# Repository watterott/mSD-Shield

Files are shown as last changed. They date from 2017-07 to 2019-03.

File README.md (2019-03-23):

# mSD-Shield
The mSD-Shield is a plug-on module with microSD socket, RTC (real time clock) with battery backup, prototyping area and optional 2.8" TFT-Display with Touch-Panel for Arduino.

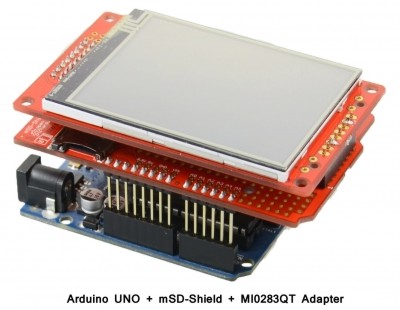
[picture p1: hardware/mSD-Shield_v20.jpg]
mSD-Shield


* microSD socket (SPI) support SD and SDHC cards
* DS1307 RTC (I2C Real-Time-Clock) with backup battery
* On-board 3.3V voltage regulator
* Optional MI0283QT-Adapter (2.8" 320x240 Display with Touch-Panel)
* Prototyping Area
* Open-Source and released under the [Creative Commons Attribution Share-Alike License](https://creativecommons.org/licenses/by-sa/4.0/).
* **[Documentation on learn.watterott.com](https://learn.watterott.com)**

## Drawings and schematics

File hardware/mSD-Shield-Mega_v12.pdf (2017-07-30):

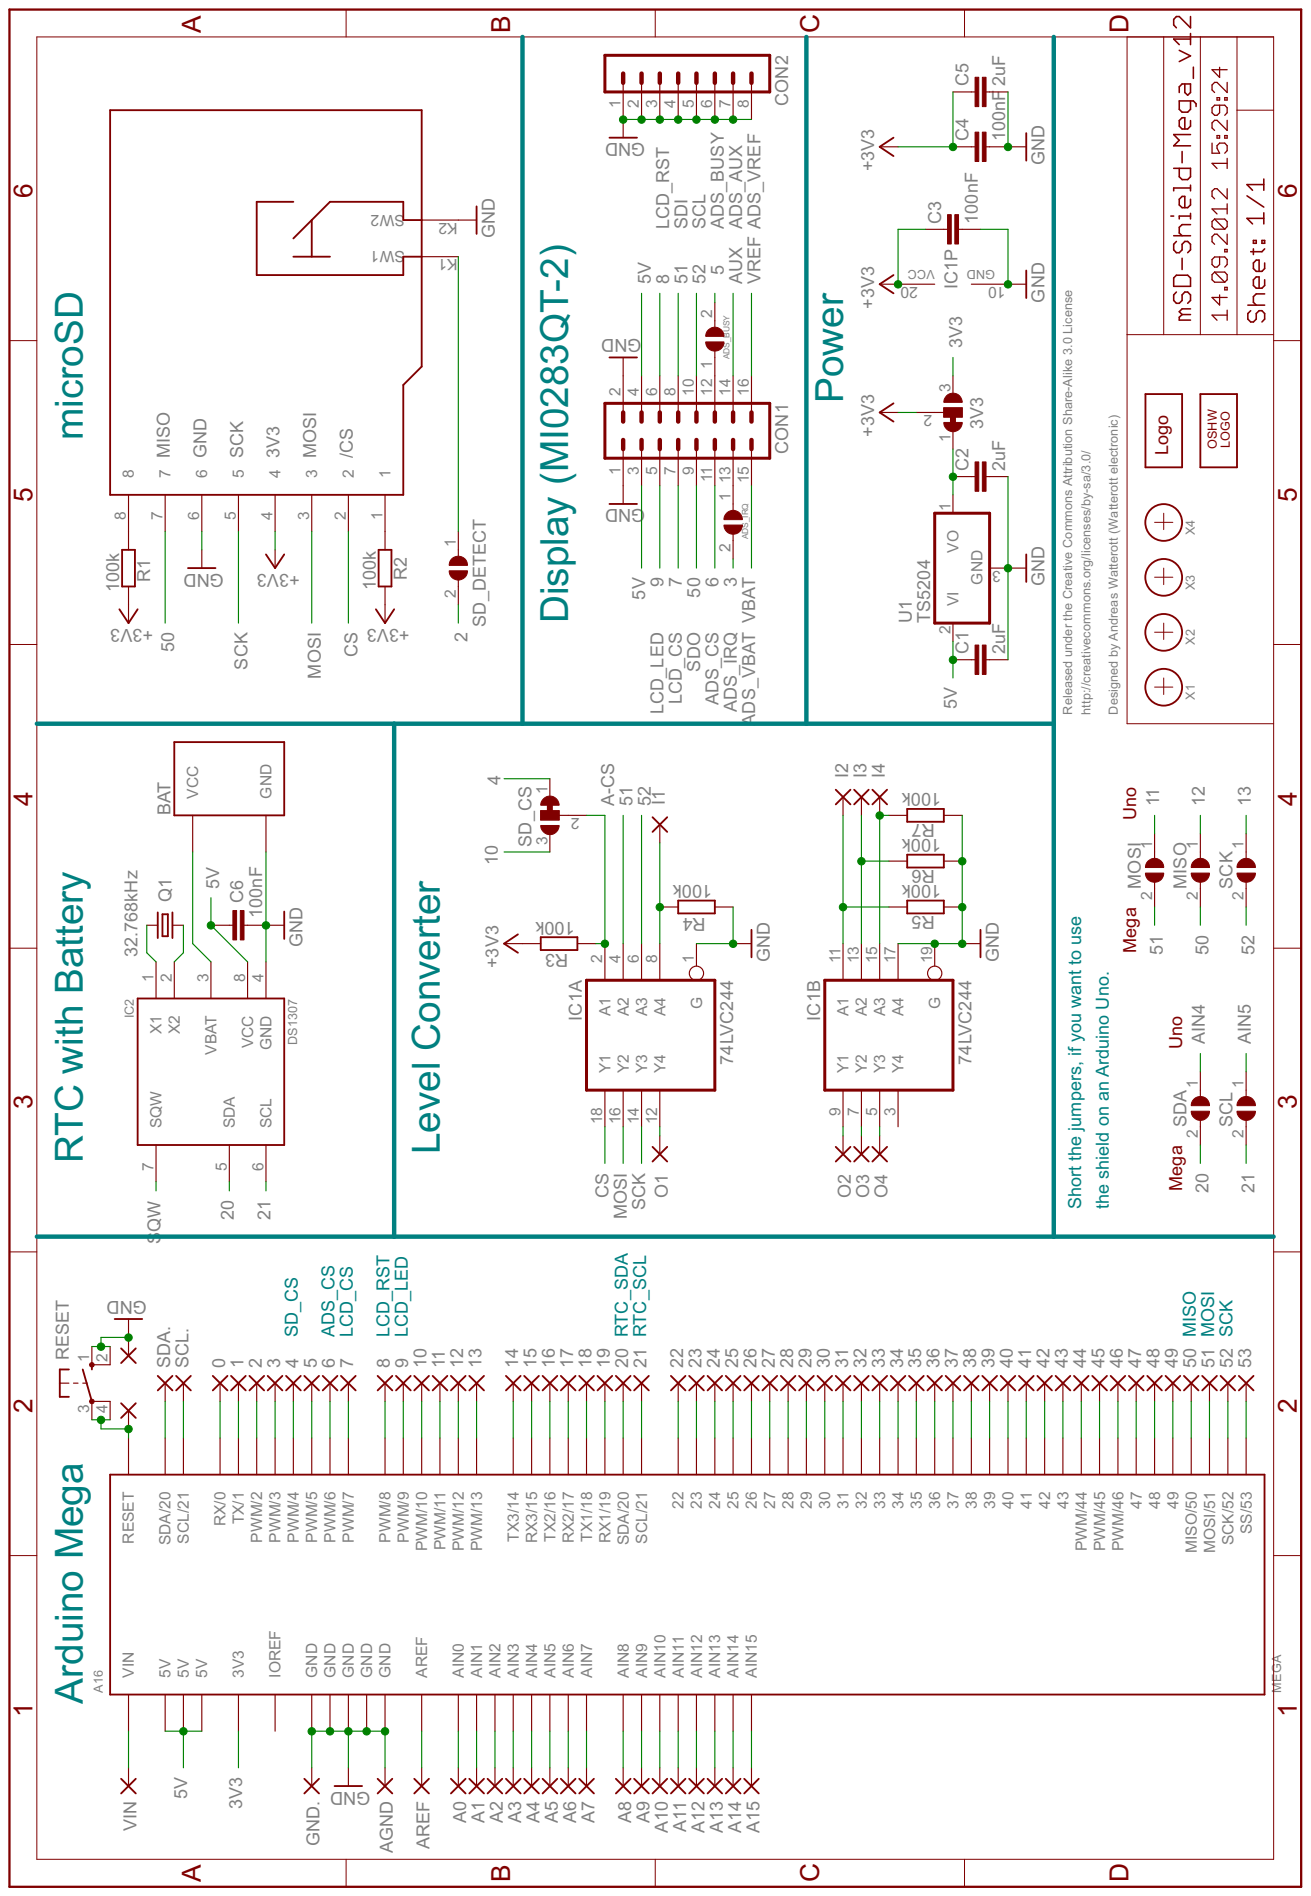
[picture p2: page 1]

Released under the Creative Commons Attribution Share-Alike 3.0 License

http://creativecommons.org/licenses/by-sa/3.0/ Designed by Andreas Watterott (Watterott electronic)

2 4 RESET SDA. SCL. GND

Uno Mega Mega Uno

Short the jumpers, if you want to use

the shield on an Arduino Uno. SCK M

PWM/3 PWM/4 PWM/5 PWM/6 PWM/7 PWM/8 PWM/9 PWM/10 PWM/11 PWM/12 PWM/13 AIN1 AIN2 AIN3 AIN4 AIN5

49 MISO/50 MOSI/51 SCK/52 SS/53

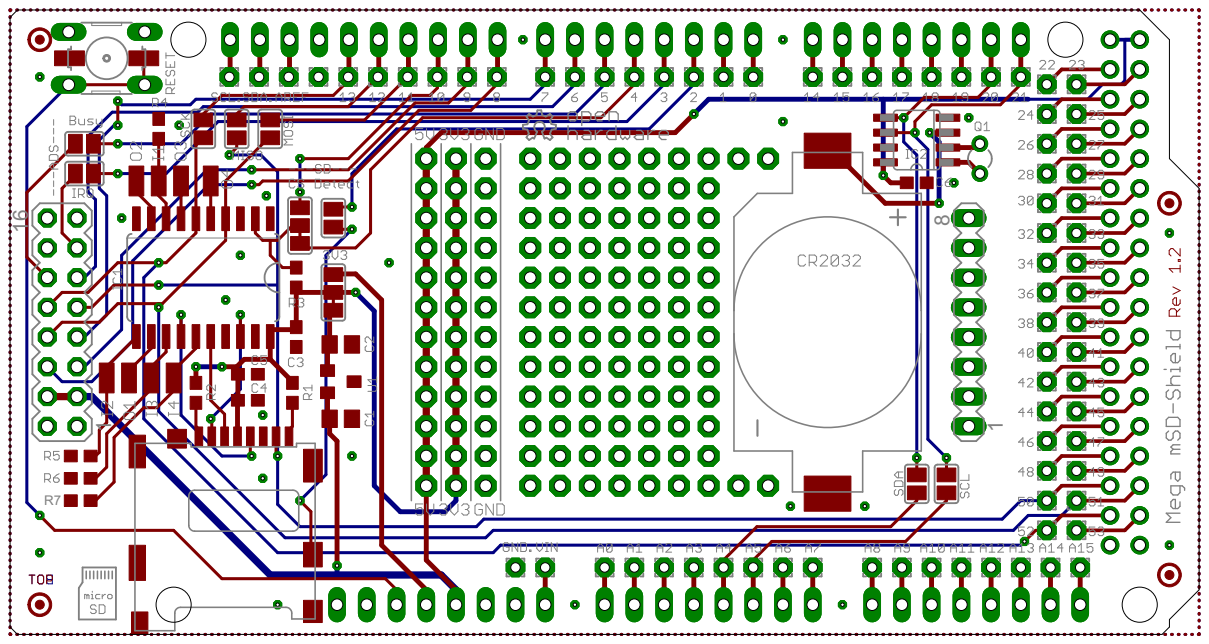
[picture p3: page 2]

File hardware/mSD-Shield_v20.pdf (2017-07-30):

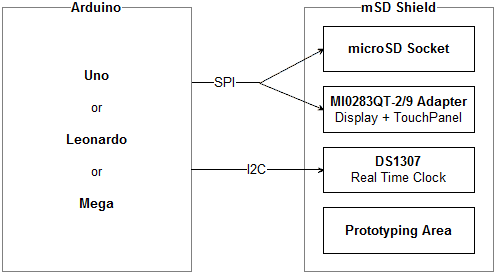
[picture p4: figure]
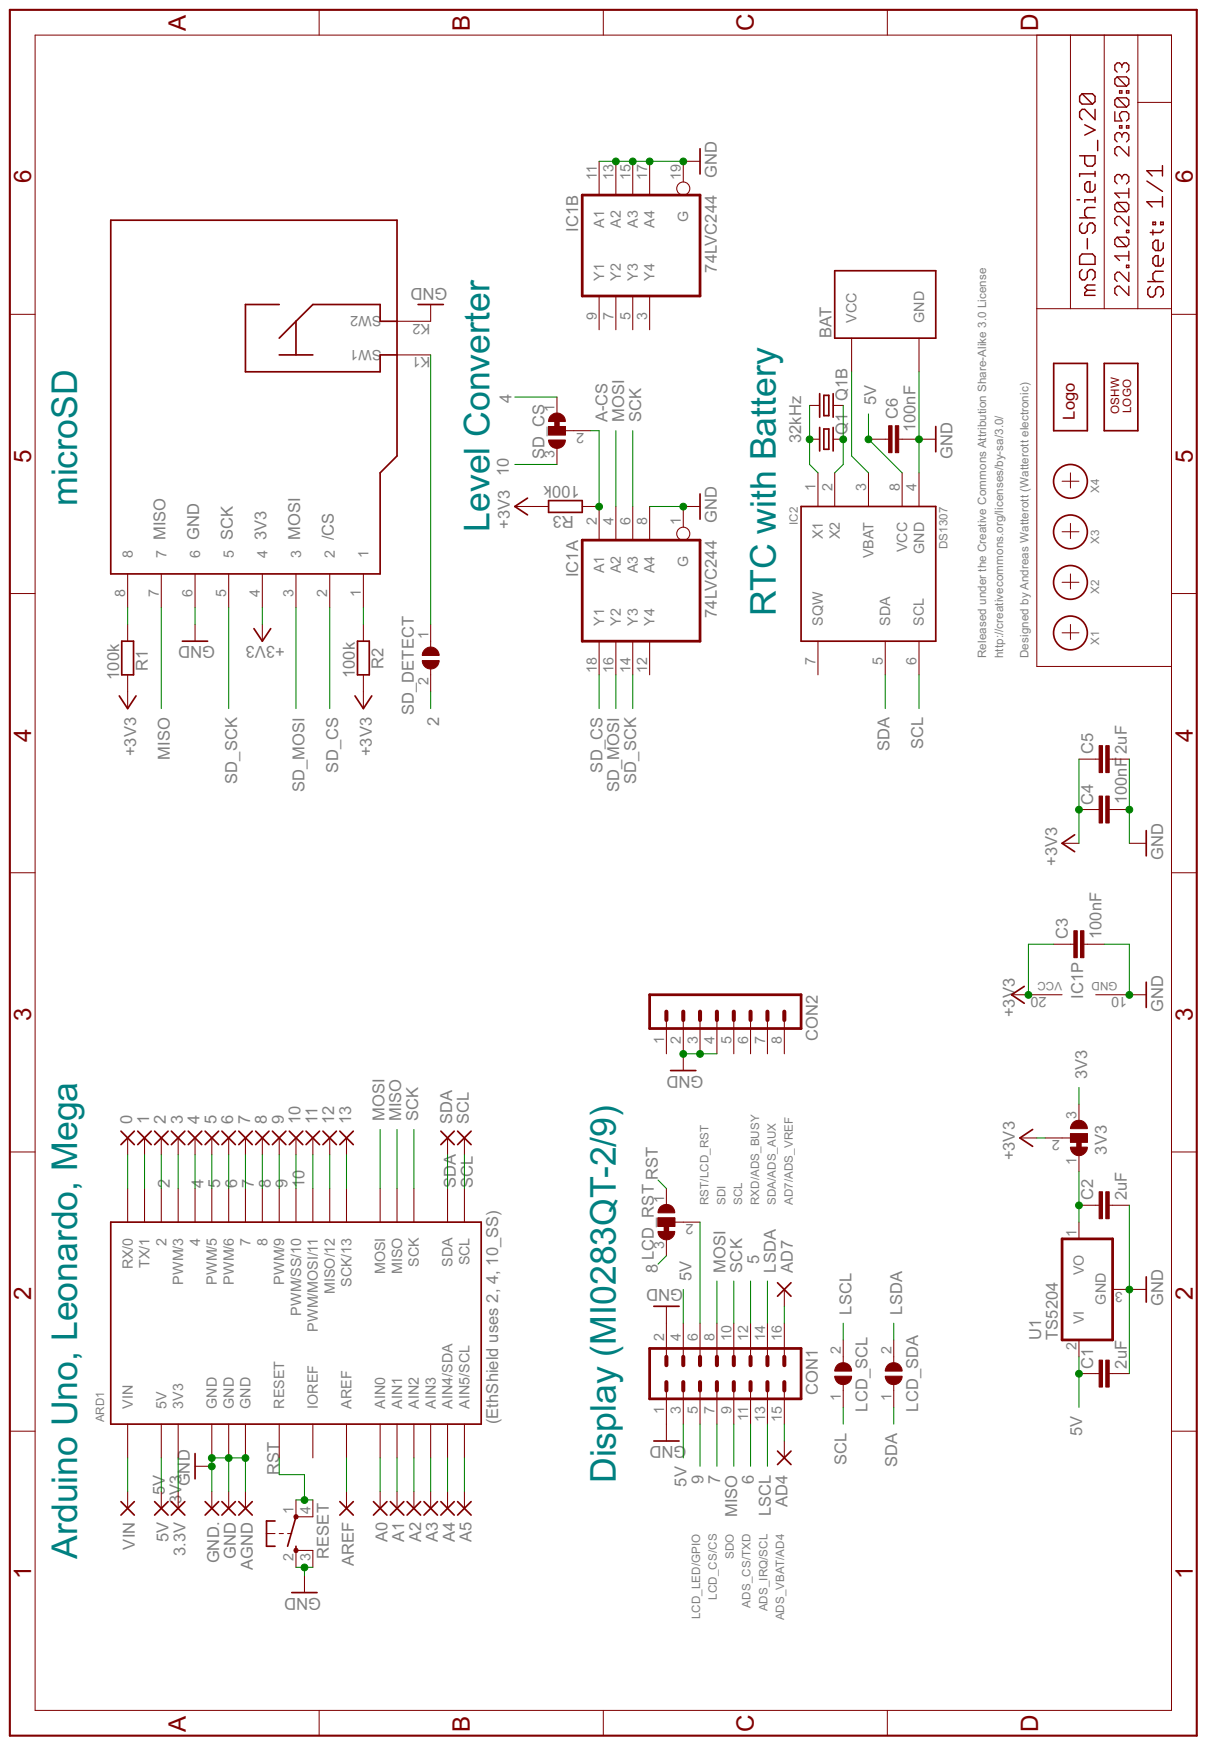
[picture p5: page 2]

Released under the Creative Commons Attribution Share-Alike 3.0 License

Arduino Uno, Leonardo, Mega microSD

Designed by Andreas Watterott (Watterott electronic)

http://creativecommons.org/licenses/by-sa/3.0/

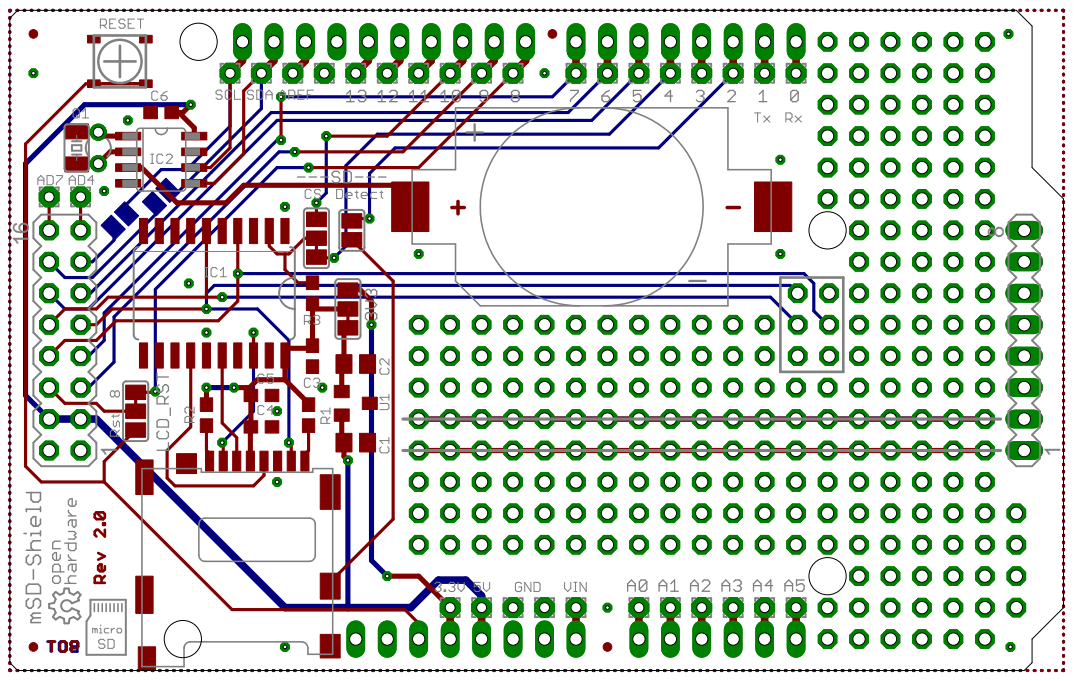
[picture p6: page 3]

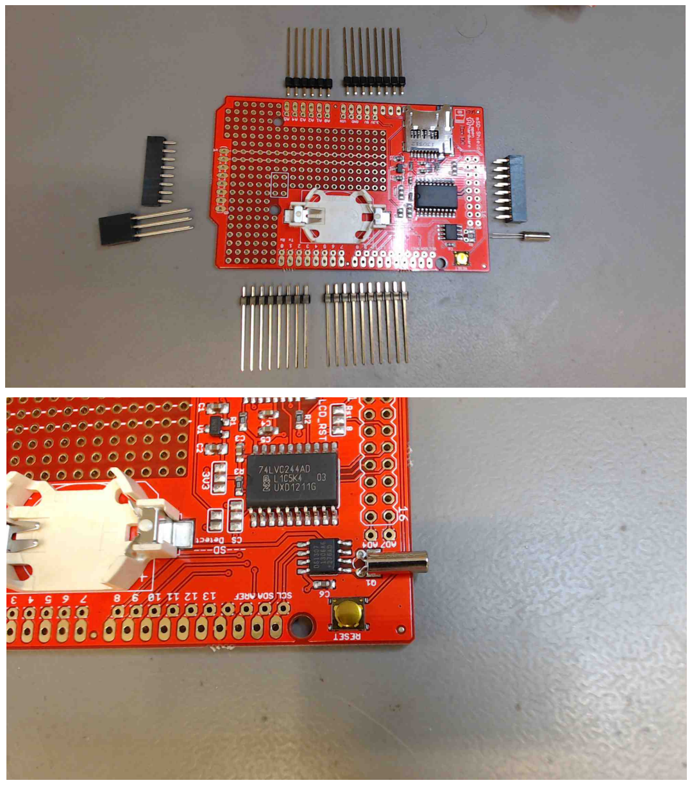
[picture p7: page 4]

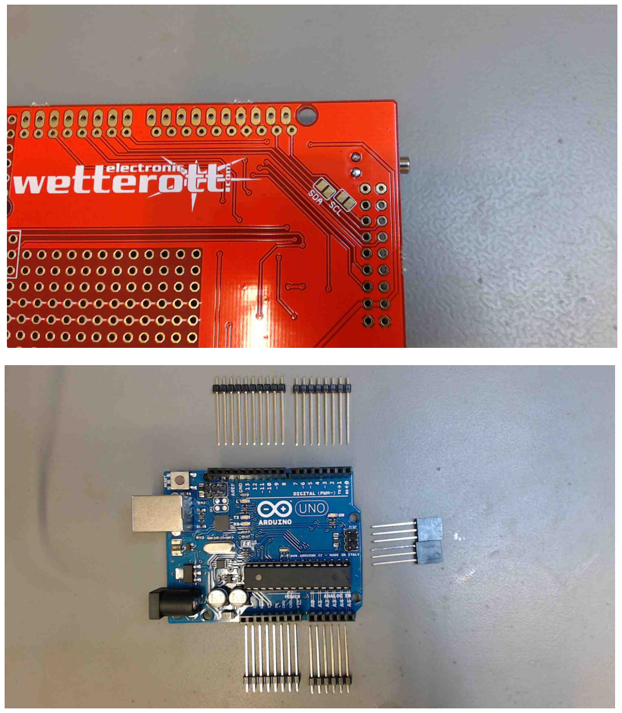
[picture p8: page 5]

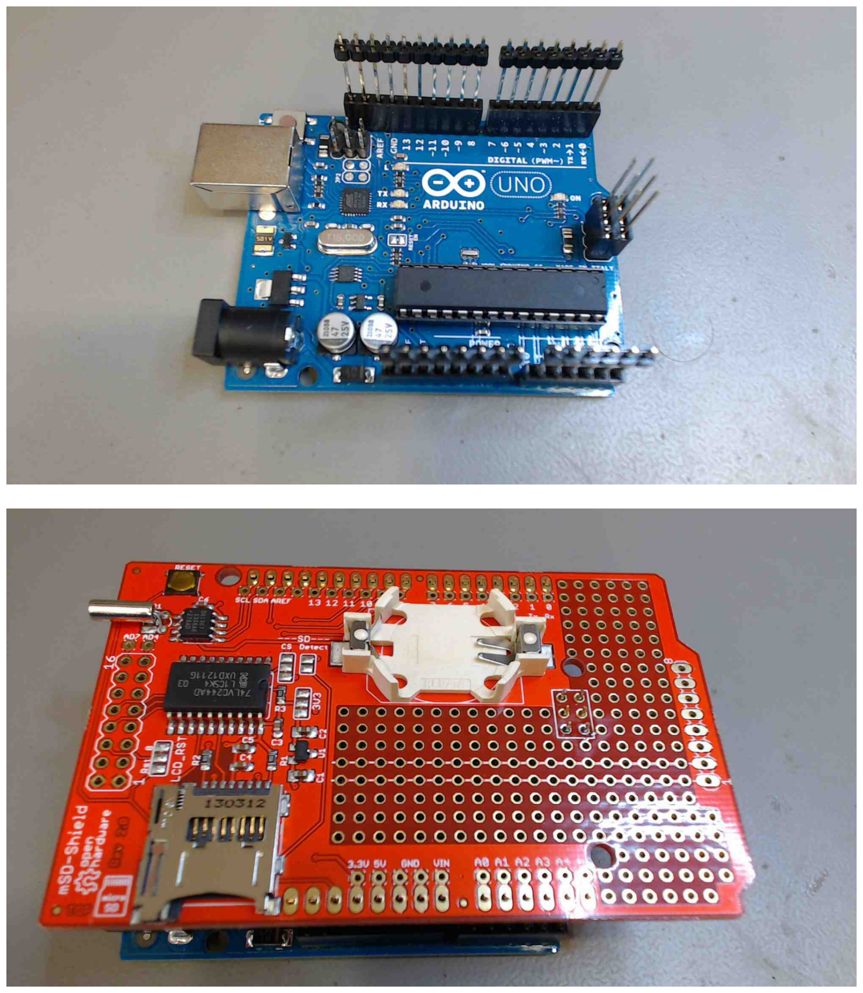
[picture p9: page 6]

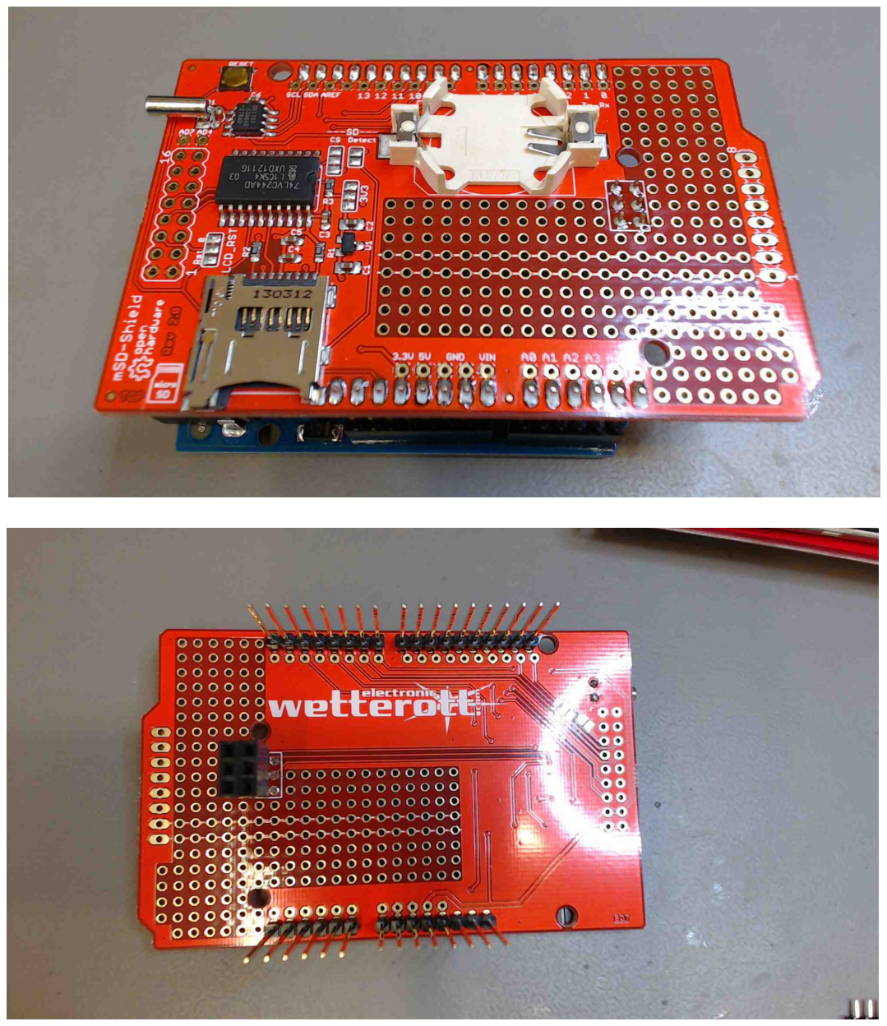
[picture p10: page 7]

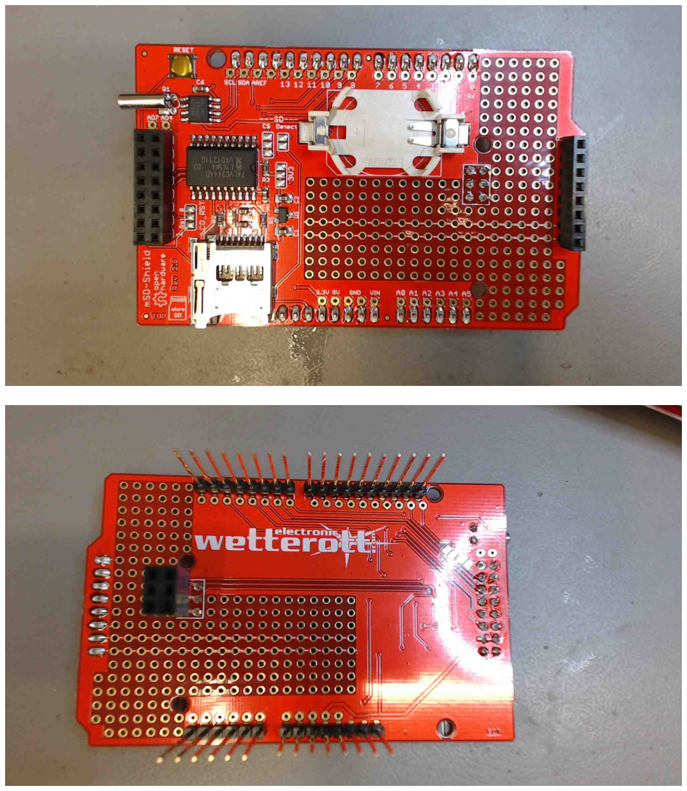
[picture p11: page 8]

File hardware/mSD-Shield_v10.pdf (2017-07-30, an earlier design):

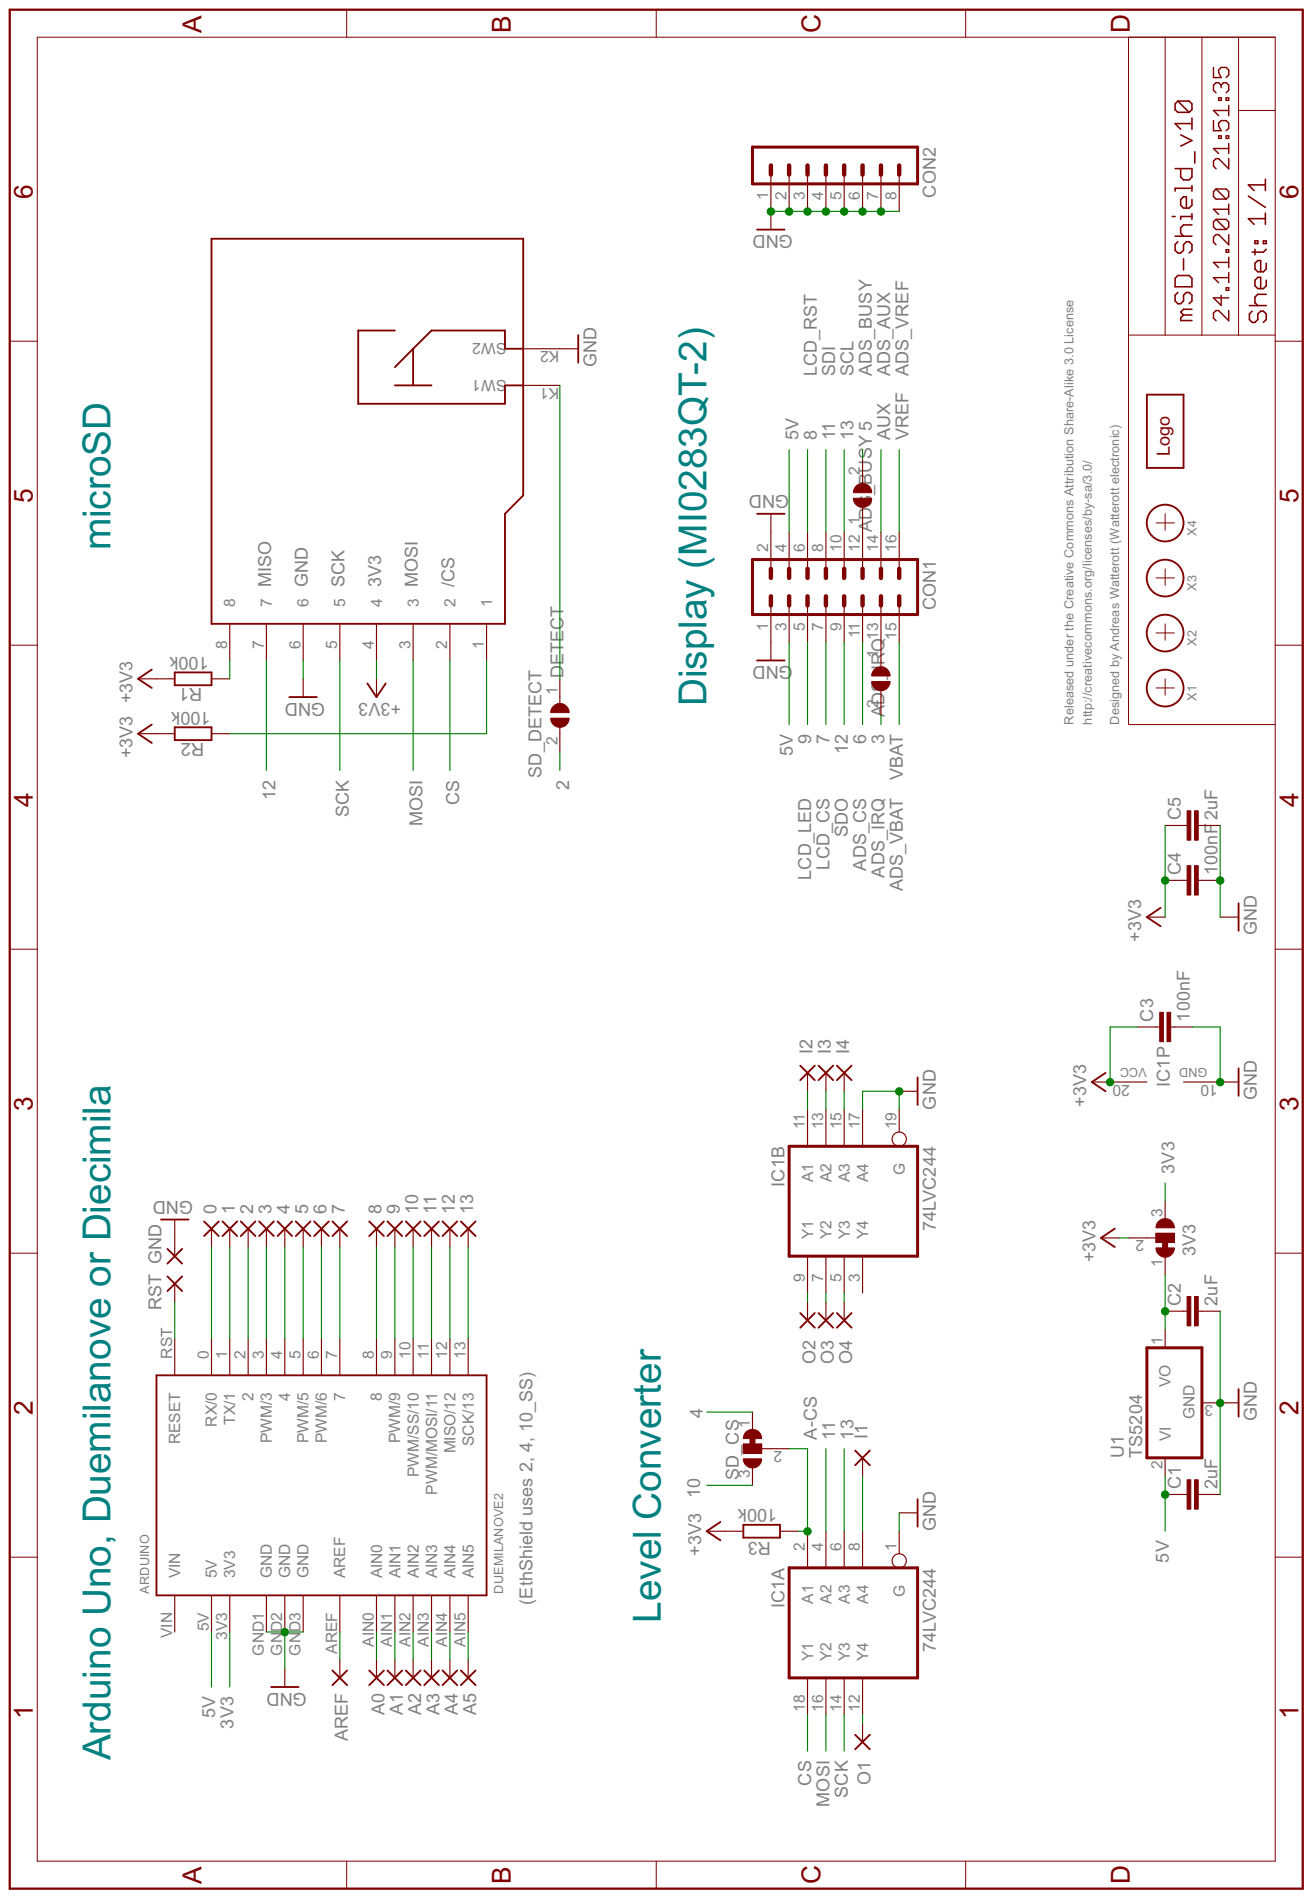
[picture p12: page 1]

TS5204 GND 2uF 2uF 100nF +3V3 GND 2uF 74LVC244 74LVC244 GND +3V3 100nF GND GND k001 +3V3 DNG 3V3+ k001 k001 +3V3 +3V3 GND DNG DNG DNG +3V3 DNG DNG Released under the Creative Commons Attribution Share-Alike 3.0 License http://creativecommons.org/licenses/by-sa/3.0/ Designed by Andreas Watterott (Watterott electronic) (EthShield uses 2, 4, 10_SS) LCD_LED LCD_CS SDO ADS_CS ADS_IRQ ADS_VBAT ADS_VREF ADS_AUX ADS_BUSY SCL SDI LCD_RST VI 2 3 VO 1 GND U1 C1 C2 C4 C5 G 1 A1 2 A2 4 A3 6 A4 8 Y4 12 Y3 14 Y2 16 Y1 18 IC1A G 19 A1 11 A2 13 A3 15 A4 17 Y4 3 Y3 5 Y2 7 Y1 9 IC1B 02 01 CCV DNG IC1P C3 3R 1 1 2 2 3 3 4 4 5 5 6 6 7 7 8 8 1 WS 1K 2 WS 2K /CS SCK MOSI MISO GND 3V3 1R2R 12345678CON2 135 246 79 810 111315 121416 CON1 3 1 2 3V3 3 1 2 SD_CS 2 1ADS_BUSY 2 1 SD_DETECT 2 1 ADS_IRQ ARDUINO DUEMILANOVE2 RX/0 0 TX/1 1 2 2 AIN0 AIN0 PWM/3 3 4 4 PWM/5 5 PWM/6 6 7 7 8 8 PWM/9 9 PWM/SS/10 10 PWM/MOSI/11 11 MISO/12 12 SCK/13 13 AIN1 AIN1 AIN2 AIN2 AIN3 AIN3 AIN4 AIN4 AIN5 AIN5 5V 5V GND GND1 GND GND2 VIN VIN 3V3 3V3 GND GND3 AREF AREF RESET RST RST GND X1 X2 X3 X4 012345678910111213 A0A1A2A3A4A5 AREF I1 I2I3I4 O1 O2 O3 O4 76 5 4 3 2 SCK SCK MOSI MOSI CS CS 13 13 12 12 11 11 9 8 5V 5V 5V 5V 3V3 3V3 DETECT AUX VBAT VREF A-CS 10 ABCD 1 2 3 4 5 6 ABCD 1 2 3 4 5 6 Logo Arduino Uno, Duemilanove or Diecimila microSD Level Converter Display (MI0283QT-2)

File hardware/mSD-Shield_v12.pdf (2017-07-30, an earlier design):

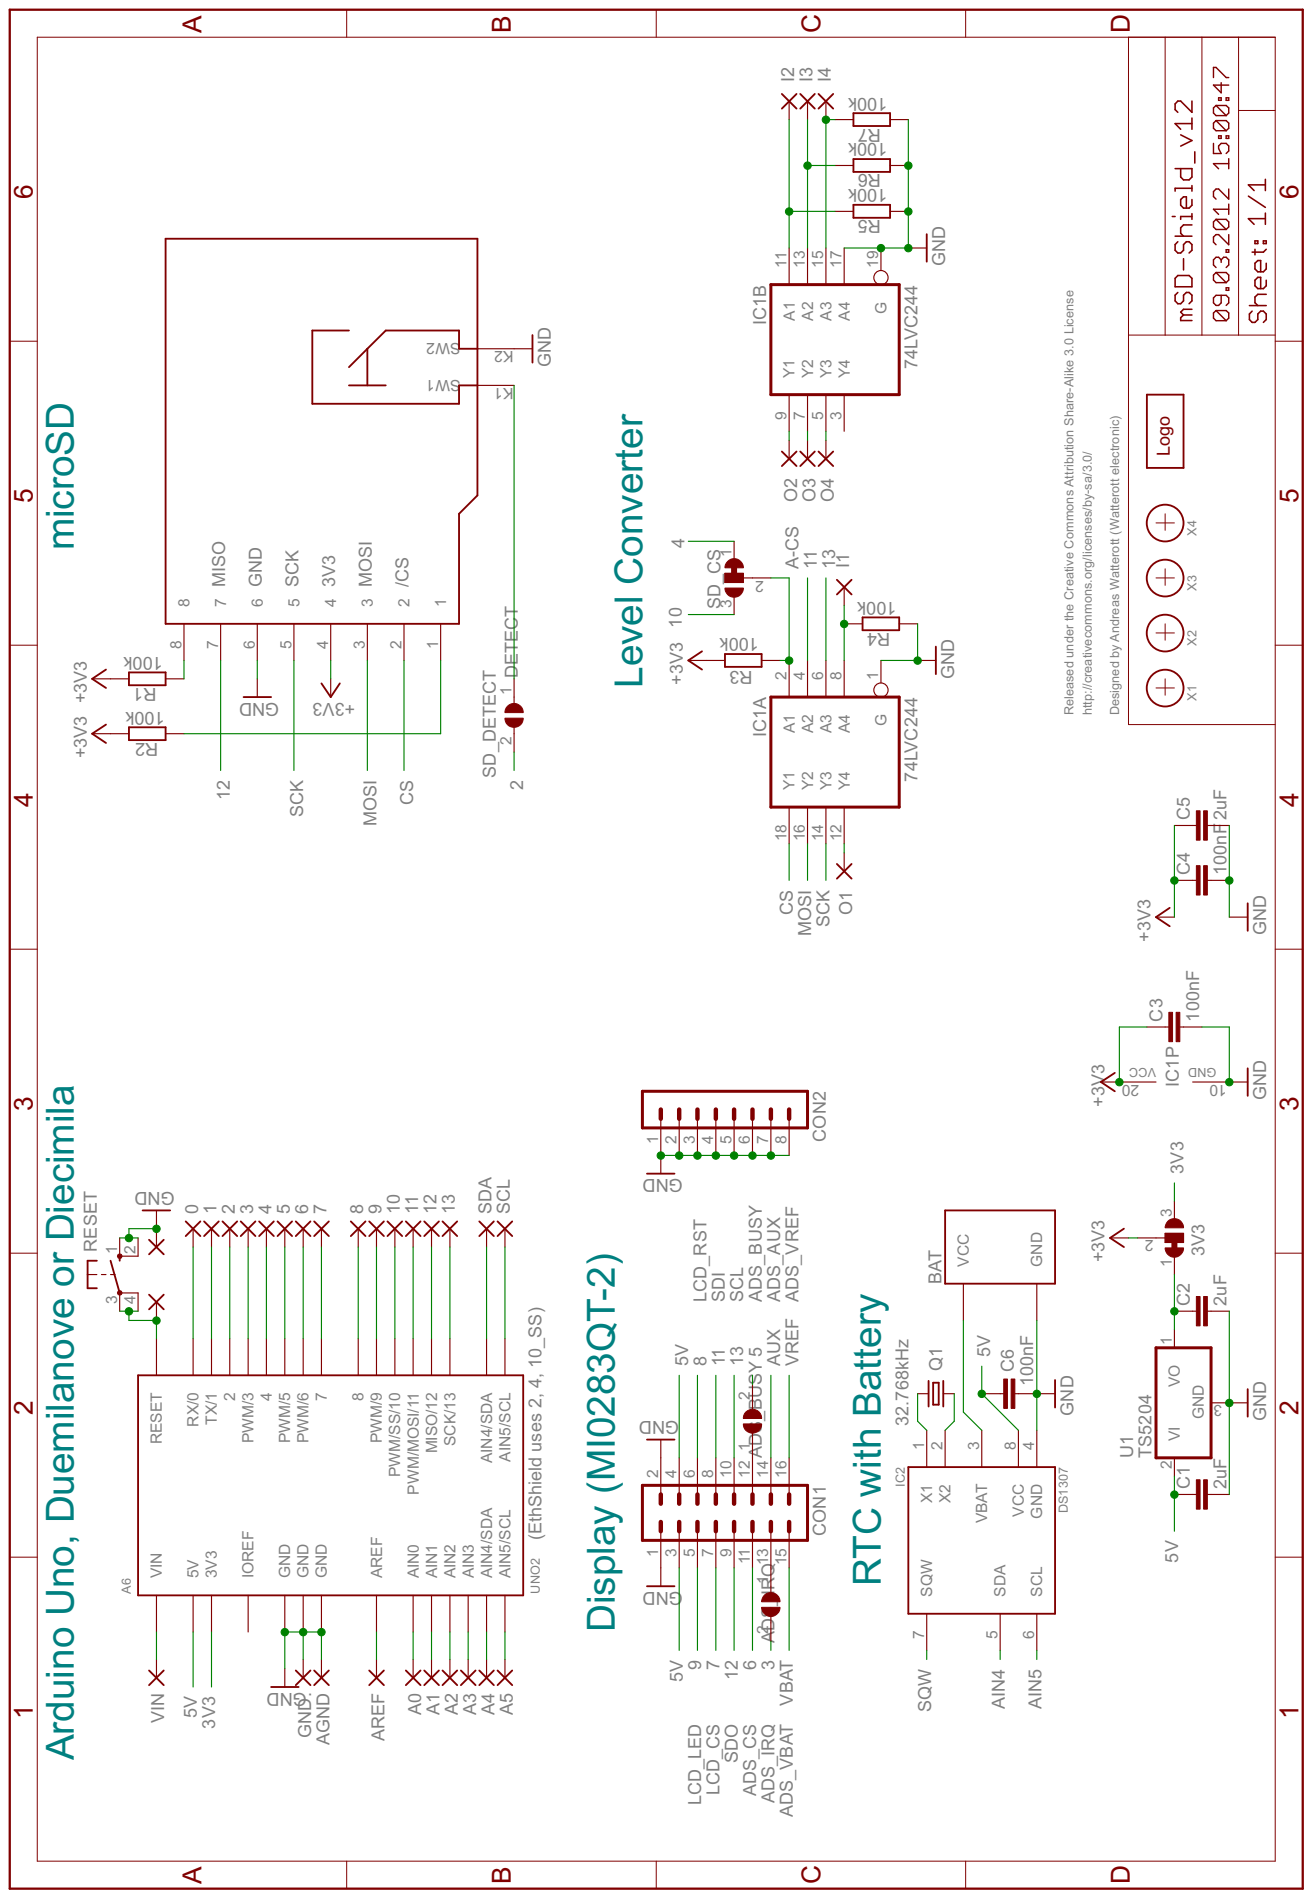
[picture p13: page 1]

Released under the Creative Commons Attribution Share-Alike 3.0 License

http://creativecommons.org/licenses/by-sa/3.0/ Designed by Andreas Watterott (Watterott electronic)

8 PWM/9 PWM/SS/10 PWM/MOSI/11 MISO/12 SCK/13 AIN1 AIN2 AIN3 AIN4/SDA

IOREF GND GND GND


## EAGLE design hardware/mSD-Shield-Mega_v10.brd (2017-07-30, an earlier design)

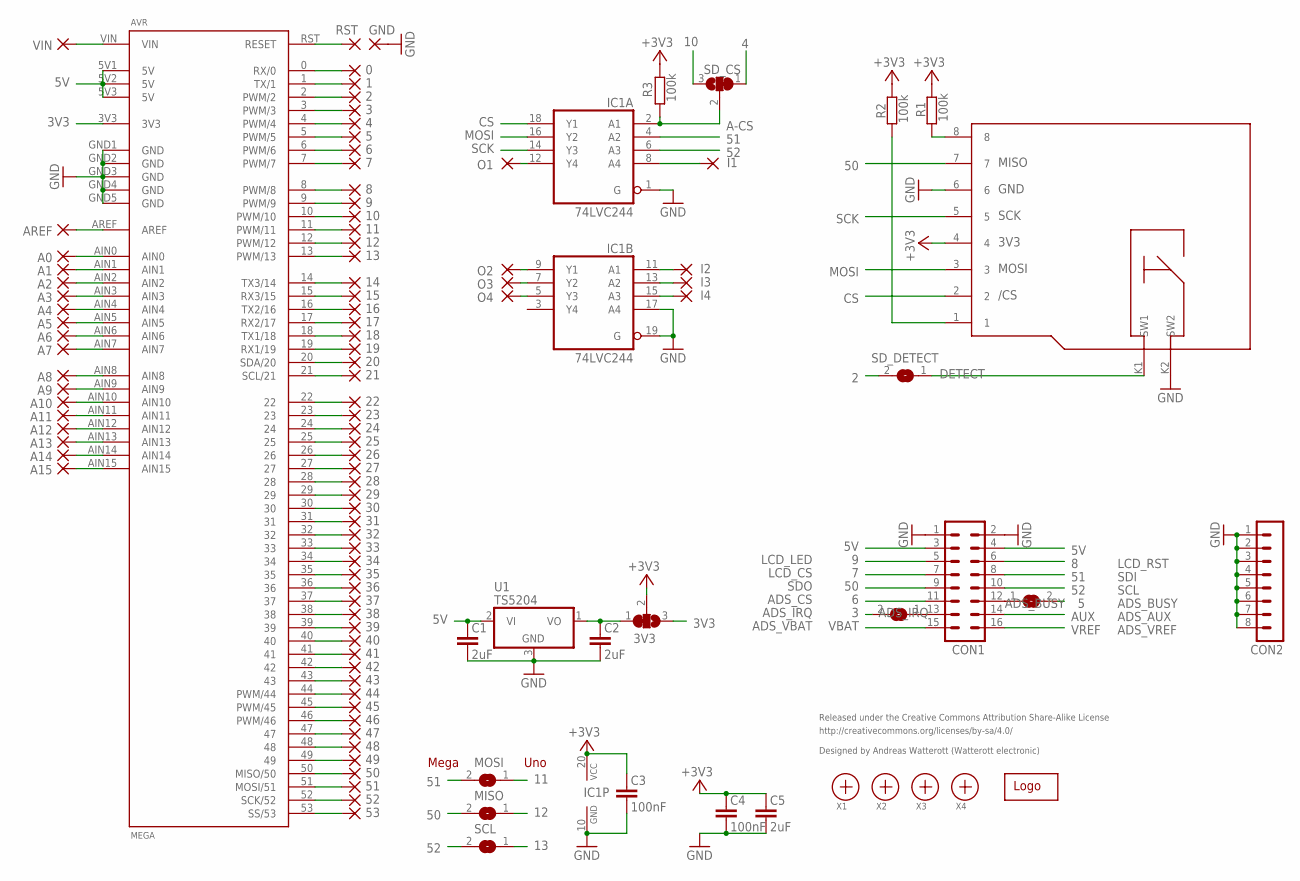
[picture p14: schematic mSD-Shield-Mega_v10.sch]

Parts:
0, 1, 2, 3, 4, 5, 6, 7, 8, 9, 10, 11, 12, 13, 14, 15, 16, 17, 18, 19, 20, 21, 22, 23, 24, 25, 26, 27, 28, 29, 30, 31, 32, 33, 34, 35, 36, 37, 38, 39, 40, 41, 42, 43, 44, 45, 46, 47, 48, 49, 50, 51, 52, 53: 1,6/0,8
3V3: SJ2W; SJ_2
A0, A1, A2, A3, A4, A5, A6, A7, A8, A9, A10, A11, A12, A13, A14, A15: 1,6/0,8
ADS_BUSY: SJ
ADS_IRQ: SJ
AREF: 1,6/0,8
AVR: MEGA
C1, C2: 2uF; C0805
C3, C4: 100nF; C0603
C5: 2uF; C0603
CON1: MA08-2
CON2: MA08-1
GND: SMD2; SMD1,27-2,54
I1, I2, I3, I4: SMD2; SMD1,27-2,54
IC1: 74LVC244; SO20W
MISO: SJ
MOSI: SJ
O1, O2, O3, O4: SMD2; SMD1,27-2,54
R1, R2, R3: 100k; R0603
RST: SMD2; SMD1,27-2,54
SCL: SJ
SD_CS: SJ2W; SJ_2
SD_DETECT: SJ
U1: TS5204; SOT23
U$1: WE-LOGO
VIN: 1,6/0,8
X1, X2, X3, X4: PASSER
X5: MICRO-SD

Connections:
0: 0.1, AVR.0 (RX/0)
1: 1.1, AVR.1 (TX/1)
2: 2.1, AVR.2 (PWM/2), SD_DETECT.2
3: 3.1, ADS_IRQ.2, AVR.3 (PWM/3)
3V3: 3V3.3, AVR.3V3
3V_OUT: 3V3.1, C2.1, U1.1 (VO)
4: 4.1, AVR.4 (PWM/4), SD_CS.1
5: 5.1, ADS_BUSY.2, AVR.5 (PWM/5)
5V: AVR.5V1 (5V), AVR.5V2 (5V), AVR.5V3 (5V), C1.1, CON1.3, CON1.4, U1.2 (VI)
6: 6.1, AVR.6 (PWM/6), CON1.11
7: 7.1, AVR.7 (PWM/7), CON1.7
8: 8.1, AVR.8 (PWM/8), CON1.6
9: 9.1, AVR.9 (PWM/9), CON1.5
10: 10.1, AVR.10 (PWM/10), SD_CS.3
11: 11.1, AVR.11 (PWM/11), MOSI.1
12: 12.1, AVR.12 (PWM/12), MISO.1
13: 13.1, AVR.13 (PWM/13), SCL.1
14: 14.1, AVR.14 (TX3/14)
15: 15.1, AVR.15 (RX3/15)
16: 16.1, AVR.16 (TX2/16)
17: 17.1, AVR.17 (RX2/17)
18: 18.1, AVR.18 (TX1/18)
19: 19.1, AVR.19 (RX1/19)
20: 20.1, AVR.20 (SDA/20)
21: 21.1, AVR.21 (SCL/21)
22: 22.1, AVR.22
23: 23.1, AVR.23
24: 24.1, AVR.24
25: 25.1, AVR.25
26: 26.1, AVR.26
27: 27.1, AVR.27
28: 28.1, AVR.28
29: 29.1, AVR.29
30: 30.1, AVR.30
31: 31.1, AVR.31
32: 32.1, AVR.32
33: 33.1, AVR.33
34: 34.1, AVR.34
35: 35.1, AVR.35
36: 36.1, AVR.36
37: 37.1, AVR.37
38: 38.1, AVR.38
39: 39.1, AVR.39
40: 40.1, AVR.40
41: 41.1, AVR.41
42: 42.1, AVR.42
43: 43.1, AVR.43
44: 44.1, AVR.44 (PWM/44)
45: 45.1, AVR.45 (PWM/45)
46: 46.1, AVR.46 (PWM/46)
47: 47.1, AVR.47
48: 48.1, AVR.48
49: 49.1, AVR.49
50: 50.1, AVR.50 (MISO/50), CON1.9, MISO.2, X5.7
51: 51.1, AVR.51 (MOSI/51), CON1.8, IC1.4 (A2), MOSI.2
52: 52.1, AVR.52 (SCK/52), CON1.10, IC1.6 (A3), SCL.2
53: 53.1, AVR.53 (SS/53)
+3V3: 3V3.2, C3.1, C4.1, C5.1, IC1.20 (VCC), R1.1, R2.1, R3.2, X5.4
A-CS: IC1.2 (A1), R3.1, SD_CS.2
ADS_BUSY: ADS_BUSY.1, CON1.12
ADS_IRQ: ADS_IRQ.1, CON1.13
AIN0: A0.1, AVR.AIN0
AIN1: A1.1, AVR.AIN1
AIN2: A2.1, AVR.AIN2
AIN3: A3.1, AVR.AIN3
AIN4: A4.1, AVR.AIN4
AIN5: A5.1, AVR.AIN5
AIN6: A6.1, AVR.AIN6
AIN7: A7.1, AVR.AIN7
AIN8: A8.1, AVR.AIN8
AIN9: A9.1, AVR.AIN9
AIN10: A10.1, AVR.AIN10
AIN11: A11.1, AVR.AIN11
AIN12: A12.1, AVR.AIN12
AIN13: A13.1, AVR.AIN13
AIN14: A14.1, AVR.AIN14
AIN15: A15.1, AVR.AIN15
AUX: CON1.14
CS: IC1.18 (Y1), X5.2
DETECT: SD_DETECT.1, X5.K1 (SW1)
GND: AVR.GND1 (GND), AVR.GND2 (GND), AVR.GND3 (GND), AVR.GND4 (GND), AVR.GND5 (GND), C1.2, C2.2, C3.2, C4.2, C5.2, CON1.1, CON1.2, CON2.1, CON2.2, CON2.3, CON2.4, CON2.5, CON2.6, CON2.7, CON2.8, GND.1, IC1.1 (G), IC1.10 (GND), IC1.17 (A4), IC1.19 (G), U1.3 (GND), X5.6, X5.K2 (SW2)
I-1: I1.1, IC1.8 (A4)
I-2: I2.1, IC1.11 (A1)
I-3: I3.1, IC1.13 (A2)
I-4: I4.1, IC1.15 (A3)
MOSI: IC1.16 (Y2), X5.3
unnamed: R2.2, X5.1
unnamed: R1.2, X5.8
unnamed: AVR.VIN, VIN.1
unnamed: AREF.1, AVR.AREF
O-1: IC1.12 (Y4), O1.1
O-2: IC1.9 (Y1), O2.1
O-3: IC1.7 (Y2), O3.1
O-4: IC1.5 (Y3), O4.1
RST: AVR.RST (RESET), RST.1
SCK: IC1.14 (Y3), X5.5
VBAT: CON1.15
VREF: CON1.16

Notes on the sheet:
Released under the Creative Commons Attribution Share-Alike License
http://creativecommons.org/licenses/by-sa/4.0/
Designed by Andreas Watterott (Watterott electronic)
LCD_LED
LCD_CS
SDO
ADS_CS
ADS_IRQ
ADS_VBAT
ADS_VREF
ADS_AUX
ADS_BUSY
SCL
SDI
LCD_RST
Uno
Mega

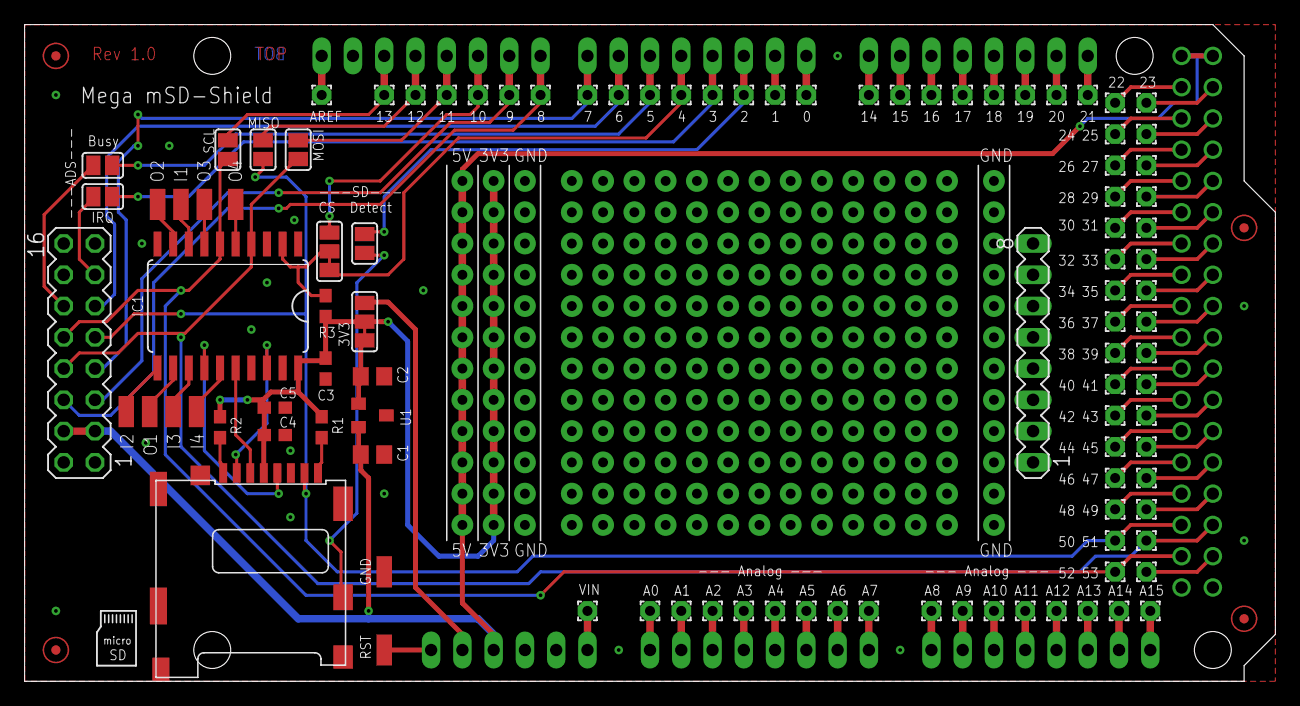
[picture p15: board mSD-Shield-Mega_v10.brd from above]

Board: 2 copper layers, 101.6 x 53.3 mm, 109 parts (1 on the bottom side), 95 nets.

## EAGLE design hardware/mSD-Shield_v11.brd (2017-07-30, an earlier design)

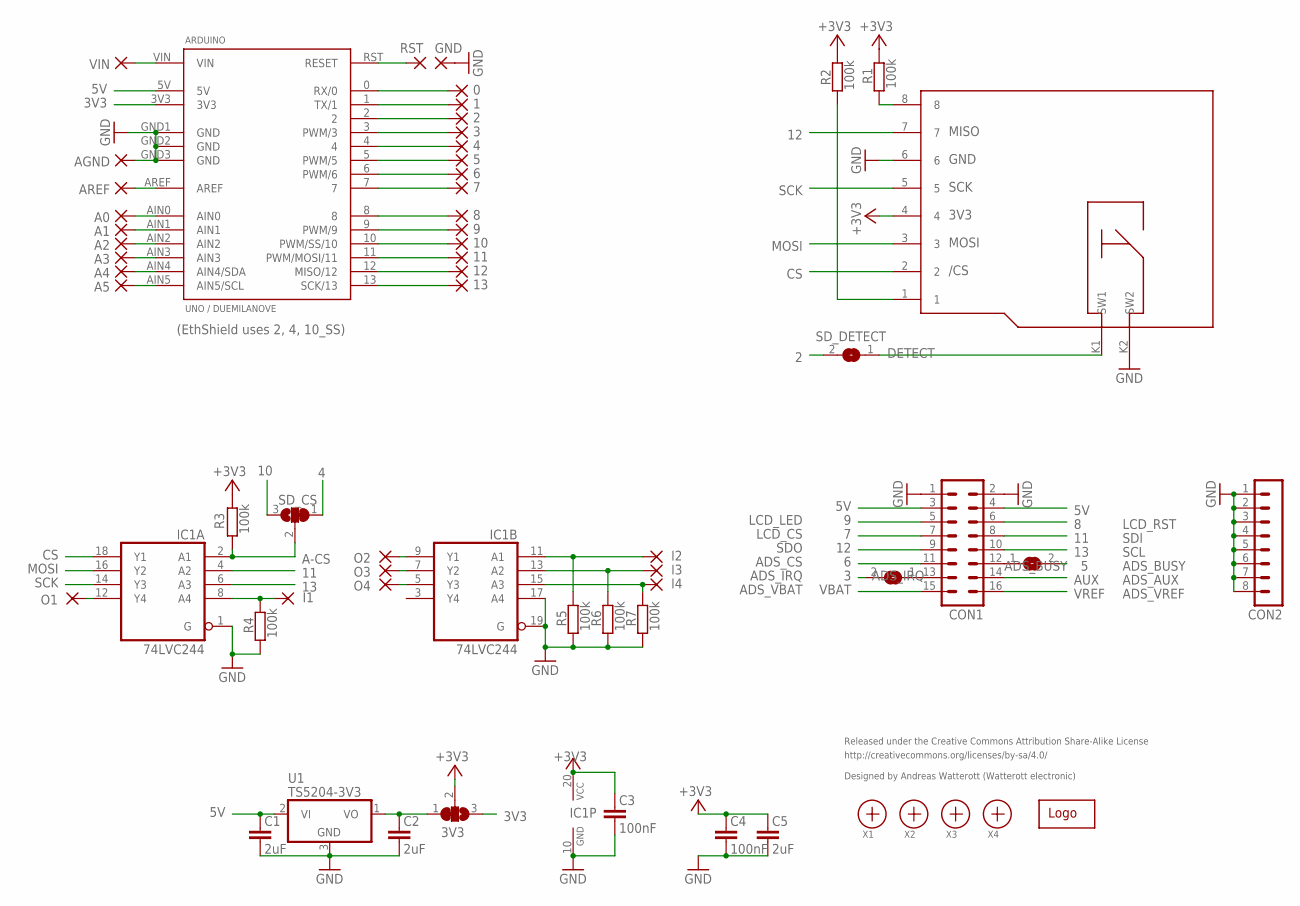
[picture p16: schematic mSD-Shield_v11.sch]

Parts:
0, 1, 2, 3, 4, 5, 6, 7, 8, 9, 10, 11, 12, 13: 1,6/0,8
3V3: SJ2W; SJ_2
A0, A1, A2, A3, A4, A5: 1,6/0,8
ADS_BUSY: SJ
ADS_IRQ: SJ
AGND: 1,6/0,8
ARDUINO: UNO / DUEMILANOVE; DUEMILANOVE2
AREF: 1,6/0,8
C1, C2: 2uF; C0805
C3, C4: 100nF; C0603
C5: 2uF; C0603
CON1: MA08-2
CON2: MA08-1
GND: SMD2; SMD1,27-2,54
I1, I2, I3, I4: SMD2; SMD1,27-2,54
IC1: 74LVC244; SO20W
O1, O2, O3, O4: SMD2; SMD1,27-2,54
R1, R2, R3, R4, R5, R6, R7: 100k; R0603
RST: SMD2; SMD1,27-2,54
SD_CS: SJ2W; SJ_2
SD_DETECT: SJ
U1: TS5204-3V3; SOT23
U$1: WE-LOGO
VIN: 1,6/0,8
X1, X2, X3, X4: PASSER
X5: MICRO-SD

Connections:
0: 0.1, ARDUINO.0 (RX/0)
1: 1.1, ARDUINO.1 (TX/1)
2: 2.1, ARDUINO.2, SD_DETECT.2
3: 3.1, ADS_IRQ.2, ARDUINO.3 (PWM/3)
3V3: 3V3.3, ARDUINO.3V3
3V_OUT: 3V3.1, C2.1, U1.1 (VO)
4: 4.1, ARDUINO.4, SD_CS.1
5: 5.1, ADS_BUSY.2, ARDUINO.5 (PWM/5)
5V: ARDUINO.5V, C1.1, CON1.3, CON1.4, U1.2 (VI)
6: 6.1, ARDUINO.6 (PWM/6), CON1.11
7: 7.1, ARDUINO.7, CON1.7
8: 8.1, ARDUINO.8, CON1.6
9: 9.1, ARDUINO.9 (PWM/9), CON1.5
10: 10.1, ARDUINO.10 (PWM/SS/10), SD_CS.3
11: 11.1, ARDUINO.11 (PWM/MOSI/11), CON1.8, IC1.4 (A2)
12: 12.1, ARDUINO.12 (MISO/12), CON1.9, X5.7
13: 13.1, ARDUINO.13 (SCK/13), CON1.10, IC1.6 (A3)
+3V3: 3V3.2, C3.1, C4.1, C5.1, IC1.20 (VCC), R1.1, R2.1, R3.2, X5.4
A-CS: IC1.2 (A1), R3.1, SD_CS.2
ADS_BUSY: ADS_BUSY.1, CON1.12
ADS_IRQ: ADS_IRQ.1, CON1.13
AIN0: A0.1, ARDUINO.AIN0
AIN1: A1.1, ARDUINO.AIN1
AIN2: A2.1, ARDUINO.AIN2
AIN3: A3.1, ARDUINO.AIN3
AIN4: A4.1, ARDUINO.AIN4 (AIN4/SDA)
AIN5: A5.1, ARDUINO.AIN5 (AIN5/SCL)
AUX: CON1.14
CS: IC1.18 (Y1), X5.2
DETECT: SD_DETECT.1, X5.K1 (SW1)
GND: AGND.1, ARDUINO.GND1 (GND), ARDUINO.GND2 (GND), ARDUINO.GND3 (GND), C1.2, C2.2, C3.2, C4.2, C5.2, CON1.1, CON1.2, CON2.1, CON2.2, CON2.3, CON2.4, CON2.5, CON2.6, CON2.7, CON2.8, GND.1, IC1.1 (G), IC1.10 (GND), IC1.17 (A4), IC1.19 (G), R4.1, R5.1, R6.1, R7.1, U1.3 (GND), X5.6, X5.K2 (SW2)
I-1: I1.1, IC1.8 (A4), R4.2
I-2: I2.1, IC1.11 (A1), R5.2
I-3: I3.1, IC1.13 (A2), R6.2
I-4: I4.1, IC1.15 (A3), R7.2
MOSI: IC1.16 (Y2), X5.3
unnamed: R2.2, X5.1
unnamed: R1.2, X5.8
unnamed: ARDUINO.VIN, VIN.1
unnamed: ARDUINO.AREF, AREF.1
O-1: IC1.12 (Y4), O1.1
O-2: IC1.9 (Y1), O2.1
O-3: IC1.7 (Y2), O3.1
O-4: IC1.5 (Y3), O4.1
RST: ARDUINO.RST (RESET), RST.1
SCK: IC1.14 (Y3), X5.5
VBAT: CON1.15
VREF: CON1.16

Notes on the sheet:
Released under the Creative Commons Attribution Share-Alike License
http://creativecommons.org/licenses/by-sa/4.0/
Designed by Andreas Watterott (Watterott electronic)
(EthShield uses 2, 4, 10_SS)
LCD_LED
LCD_CS
SDO
ADS_CS
ADS_IRQ
ADS_VBAT
ADS_VREF
ADS_AUX
ADS_BUSY
SCL
SDI
LCD_RST

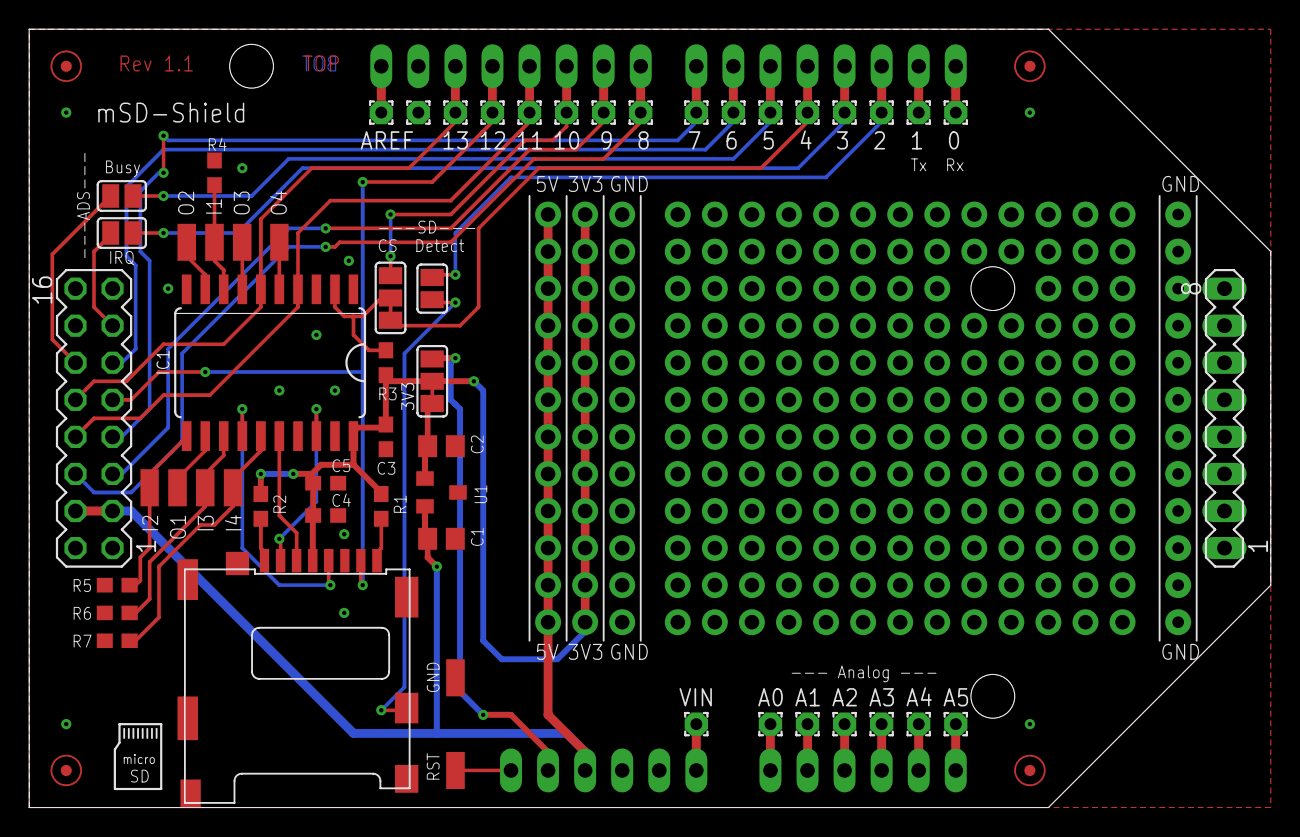
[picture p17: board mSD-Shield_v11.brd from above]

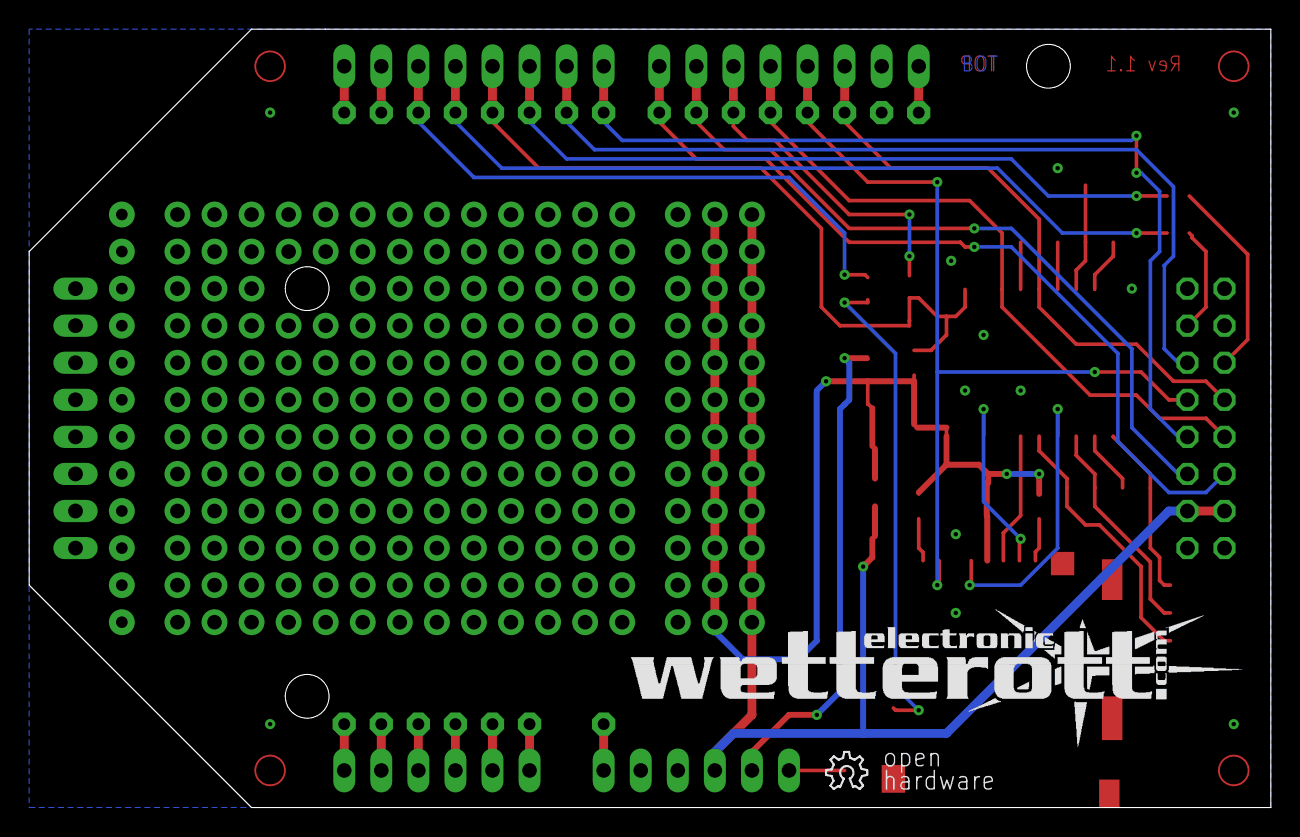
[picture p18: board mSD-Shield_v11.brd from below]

Board: 2 copper layers, 85.1 x 53.3 mm, 62 parts (2 on the bottom side), 45 nets.

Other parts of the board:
LOGO1: OSHW_LOGO_6MILX0100-NT; OSHW_6X100_NOTEXT

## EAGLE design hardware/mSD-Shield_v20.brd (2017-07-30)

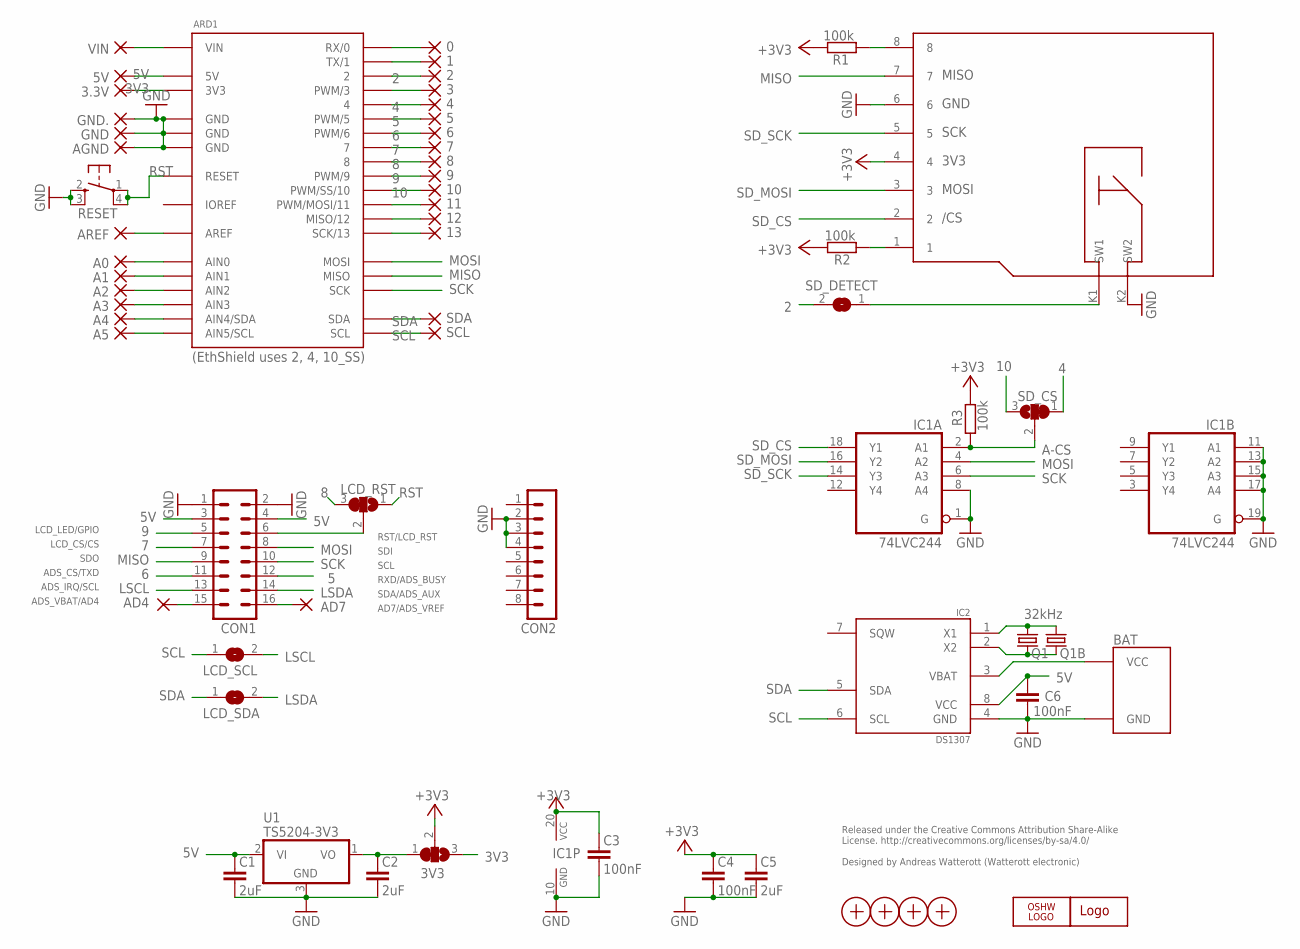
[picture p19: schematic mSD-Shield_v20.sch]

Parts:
0, 1, 2, 3, 3.3V, 4, 5, 5V, 6, 7, 8, 9, 10, 11, 12, 13: 1,6/0,8
3V3: SJ2W; SJ_2
A0, A1, A2, A3, A4, A5: 1,6/0,8
AD4, AD7: 1,6/0,8
AGND: 1,6/0,8
ARD1: UNO_ISP2
AREF: 1,6/0,8
BAT: 4UC-05581
C1, C2: 2uF; C0805
C3, C4, C6: 100nF; C0603
C5: 2uF; C0603
CON1: MA08-2
CON2: MA08-1
GND, GND.: 1,6/0,8
IC1: 74LVC244; SO20W
IC2: DS1307; SO8
LCD_RST: SJ2W; SJ_2
LCD_SCL: SJ
LCD_SDA: SJ
LOGO2: WE-LOGOPLACE; WE-LOGO
LOGO3: OSHW_LOGO_6MILX0100-NT; OSHW_6X100_NOTEXT
Q1: 32kHz; TC26V
Q1B: 32kHz; ZM315
R1, R2, R3: 100k; R0603
RESET: SW4S; SW_SMD4
SCL: 1,6/0,8
SDA: 1,6/0,8
SD_CS: SJ2W; SJ_2
SD_DETECT: SJ
U1: TS5204-3V3; SOT23
VIN: 1,6/0,8
X1, X2, X3, X4: PASSER
X5: MICRO-SD

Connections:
0: 0.1, ARD1.0 (RX/0)
1: 1.1, ARD1.1 (TX/1)
2: 2.1, ARD1.2, SD_DETECT.2
3: 3.1, ARD1.3 (PWM/3)
3V3: 3.3V.1, 3V3.3, ARD1.3V3
3V_OUT: 3V3.1, C2.1, U1.1 (VO)
4: 4.1, ARD1.4, SD_CS.1
5: 5.1, ARD1.5 (PWM/5), CON1.12
5V: 5V.1, ARD1.5V, C1.1, C6.2, CON1.3, CON1.4, IC2.8 (VCC), U1.2 (VI)
6: 6.1, ARD1.6 (PWM/6), CON1.11
7: 7.1, ARD1.7, CON1.7
8: 8.1, ARD1.8, LCD_RST.3
9: 9.1, ARD1.9 (PWM/9), CON1.5
10: 10.1, ARD1.10 (PWM/SS/10), SD_CS.3
11: 11.1, ARD1.11 (PWM/MOSI/11)
12: 12.1, ARD1.12 (MISO/12)
13: 13.1, ARD1.13 (SCK/13)
+3V3: 3V3.2, C3.1, C4.1, C5.1, IC1.20 (VCC), R1.1, R2.1, R3.2, X5.4
A-CS: IC1.2 (A1), R3.1, SD_CS.2
AD4: AD4.1, CON1.15
AD7: AD7.1, CON1.16
AIN0: A0.1, ARD1.AIN0
AIN1: A1.1, ARD1.AIN1
AIN2: A2.1, ARD1.AIN2
AIN3: A3.1, ARD1.AIN3
AIN4: A4.1, ARD1.AIN4 (AIN4/SDA)
AIN5: A5.1, ARD1.AIN5 (AIN5/SCL)
AREF: ARD1.AREF, AREF.1
GND: AGND.1, ARD1.GND@1 (GND), ARD1.GND@2 (GND), ARD1.GND@3 (GND), BAT.GND, C1.2, C2.2, C3.2, C4.2, C5.2, C6.1, CON1.1, CON1.2, CON2.2, CON2.3, CON2.4, GND.1, GND..1, IC1.1 (G), IC1.8 (A4), IC1.10 (GND), IC1.11 (A1), IC1.13 (A2), IC1.15 (A3), IC1.17 (A4), IC1.19 (G), IC2.4 (GND), RESET.2 (S), RESET.3 (S1), U1.3 (GND), X5.6, X5.K2 (SW2)
IOREF: ARD1.IOREF
LCD_RST: CON1.6, LCD_RST.2
LSCL: CON1.13, LCD_SCL.2
LSDA: CON1.14, LCD_SDA.2
MISO: ARD1.MISO, CON1.9, X5.7
MOSI: ARD1.MOSI, CON1.8, IC1.4 (A2)
unnamed: R2.2, X5.1
unnamed: R1.2, X5.8
RST: ARD1.RST (RESET), LCD_RST.1, RESET.1, RESET.4 (P1)
SCK: ARD1.SCK, CON1.10, IC1.6 (A3)
SCL: ARD1.SCL, IC2.6 (SCL), LCD_SCL.1, SCL.1
SDA: ARD1.SDA, IC2.5 (SDA), LCD_SDA.1, SDA.1
SD_CS: IC1.18 (Y1), X5.2
SD_DET: SD_DETECT.1, X5.K1 (SW1)
SD_MOSI: IC1.16 (Y2), X5.3
SD_SCK: IC1.14 (Y3), X5.5
VBAT: BAT.VCC, IC2.3 (VBAT)
VIN: ARD1.VIN, VIN.1
X1: IC2.1 (X1), Q1.2, Q1B.2
X2: IC2.2 (X2), Q1.1, Q1B.1

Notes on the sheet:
Released under the Creative Commons Attribution Share-Alike License. http://creativecommons.org/licenses/by-sa/4.0/ Designed by Andreas Watterott (Watterott electronic)
(EthShield uses 2, 4, 10_SS)
LCD_LED/GPIO
LCD_CS/CS
SDO
ADS_CS/TXD
ADS_IRQ/SCL
ADS_VBAT/AD4
AD7/ADS_VREF
SDA/ADS_AUX
RXD/ADS_BUSY
SCL
SDI
RST/LCD_RST

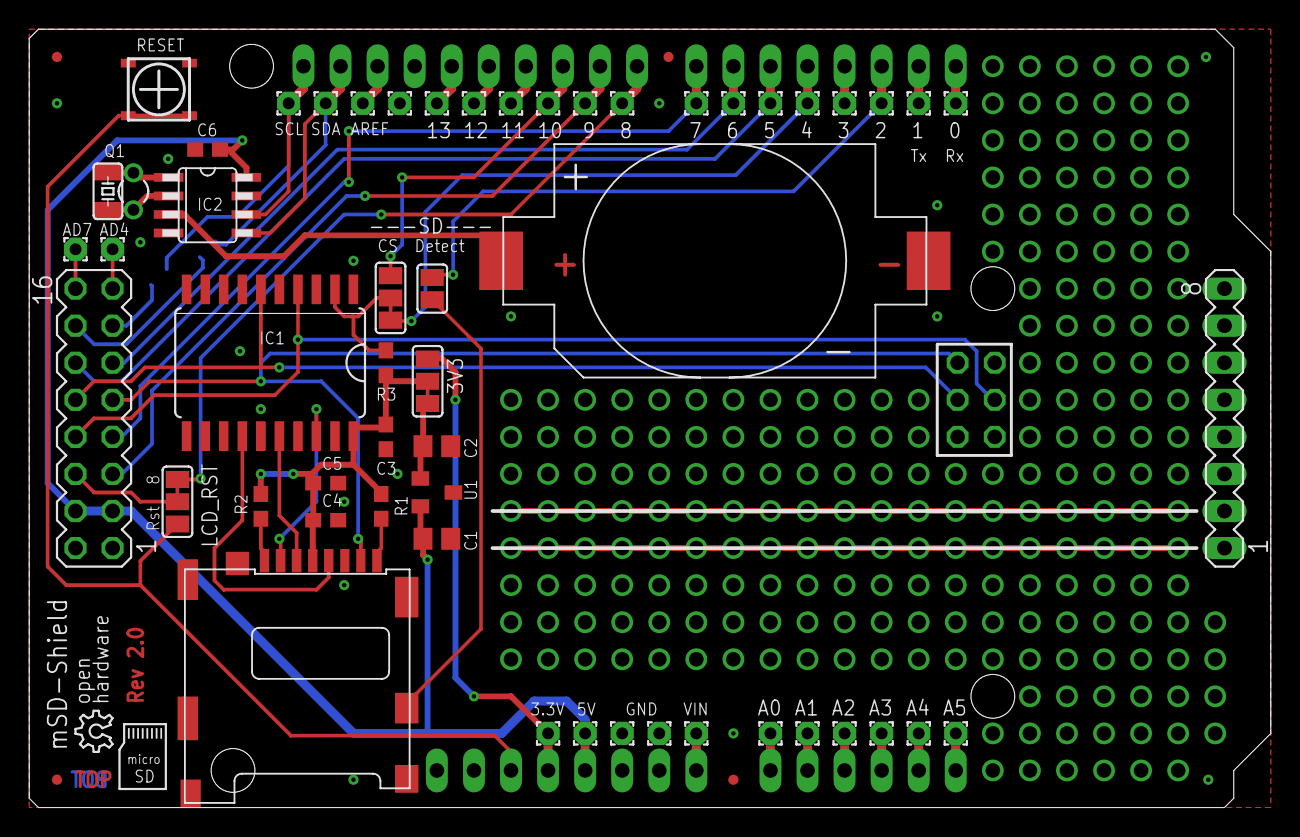
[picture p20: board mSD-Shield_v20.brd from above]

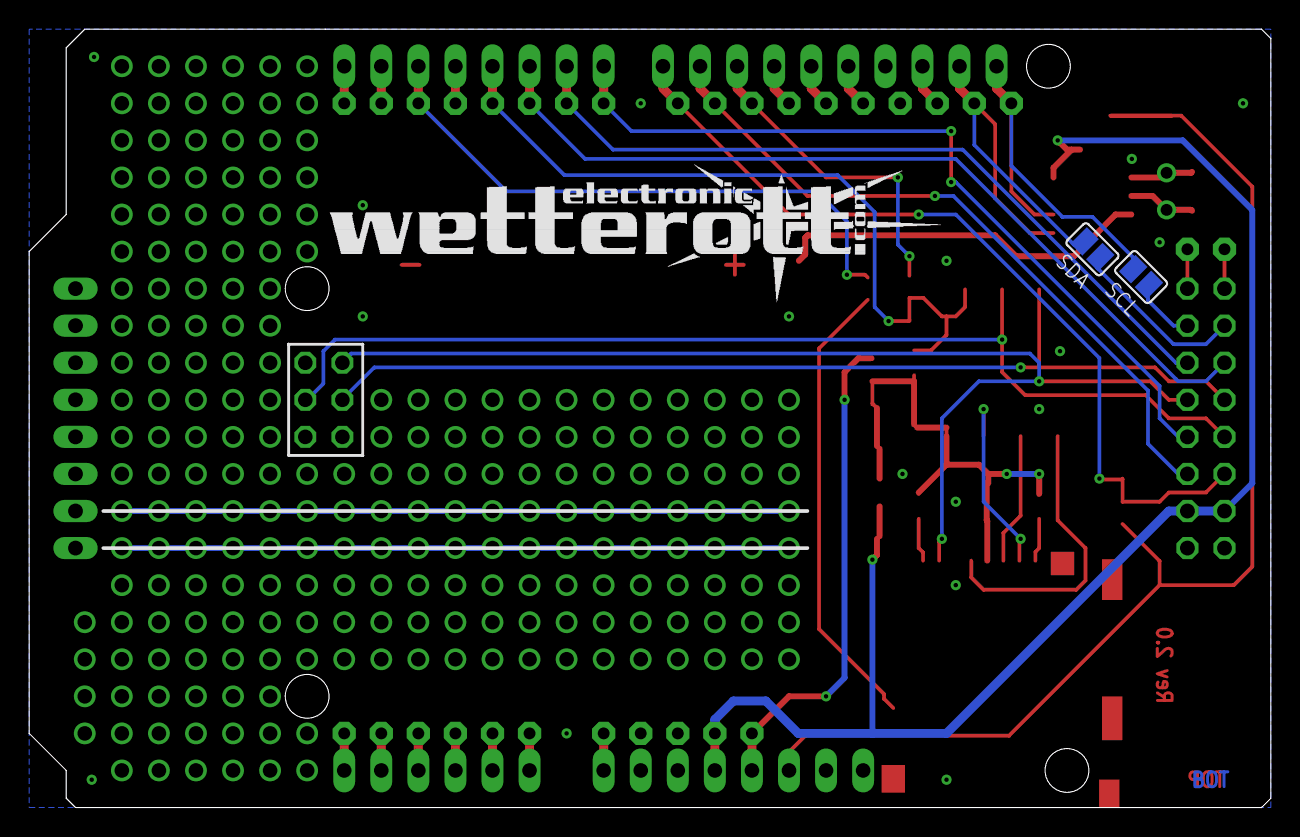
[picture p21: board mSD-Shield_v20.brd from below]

Board: 2 copper layers, 85.1 x 53.3 mm, 63 parts (3 on the bottom side), 48 nets.
